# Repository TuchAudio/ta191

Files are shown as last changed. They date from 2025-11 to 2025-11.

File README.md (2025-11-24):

# ta191
Low Noise, improved Moving-Coil Phono Pre-Amp

## Purpose
An optional _previous_ stage for **MM Phono preamps** like [TuchAudio 101b](../../../ta101b), allowing the use of **Moving Coil** cartridges. _With suitable wiring_ it could be used with other preamps as well, like the [103](../../../ta103) board.

A _built-in relay_ allows the **same input connector** to be used with both **MC** (thru amplification) and **MM cartridges** (_bypassing_ it straight to the MM Phono stage)

## Design
The use of **four _common-base_ stages in parallel**  provides **low input impedance** (100 Ω) and **improved _signal-to-noise_ ratio** (by 6 dB).

_Symmetrical power supply_ thru **serial regulation** provides high PSRR.

## Specs
- **Power supply:** +/-9V, _symmetrical_ (just a few mA)
- **Gain:** x33 (+34 dB)
- **Input Sensitivity:** 0.11 mV over 100 Ω (for a 3.6 mV output, suitable for [TuchAudio 101b preamp](../../../ta101b) or [TuchAudio 103](../../../ta103))
- **Nominal Output level:** 3.6 mV over 110 kΩ (from a 0.11 mV input)
- **Output impedance:** 3.3 kΩ. _Lower load impedances are allowed, but diminished output level and impaired bass response are to be expected_.

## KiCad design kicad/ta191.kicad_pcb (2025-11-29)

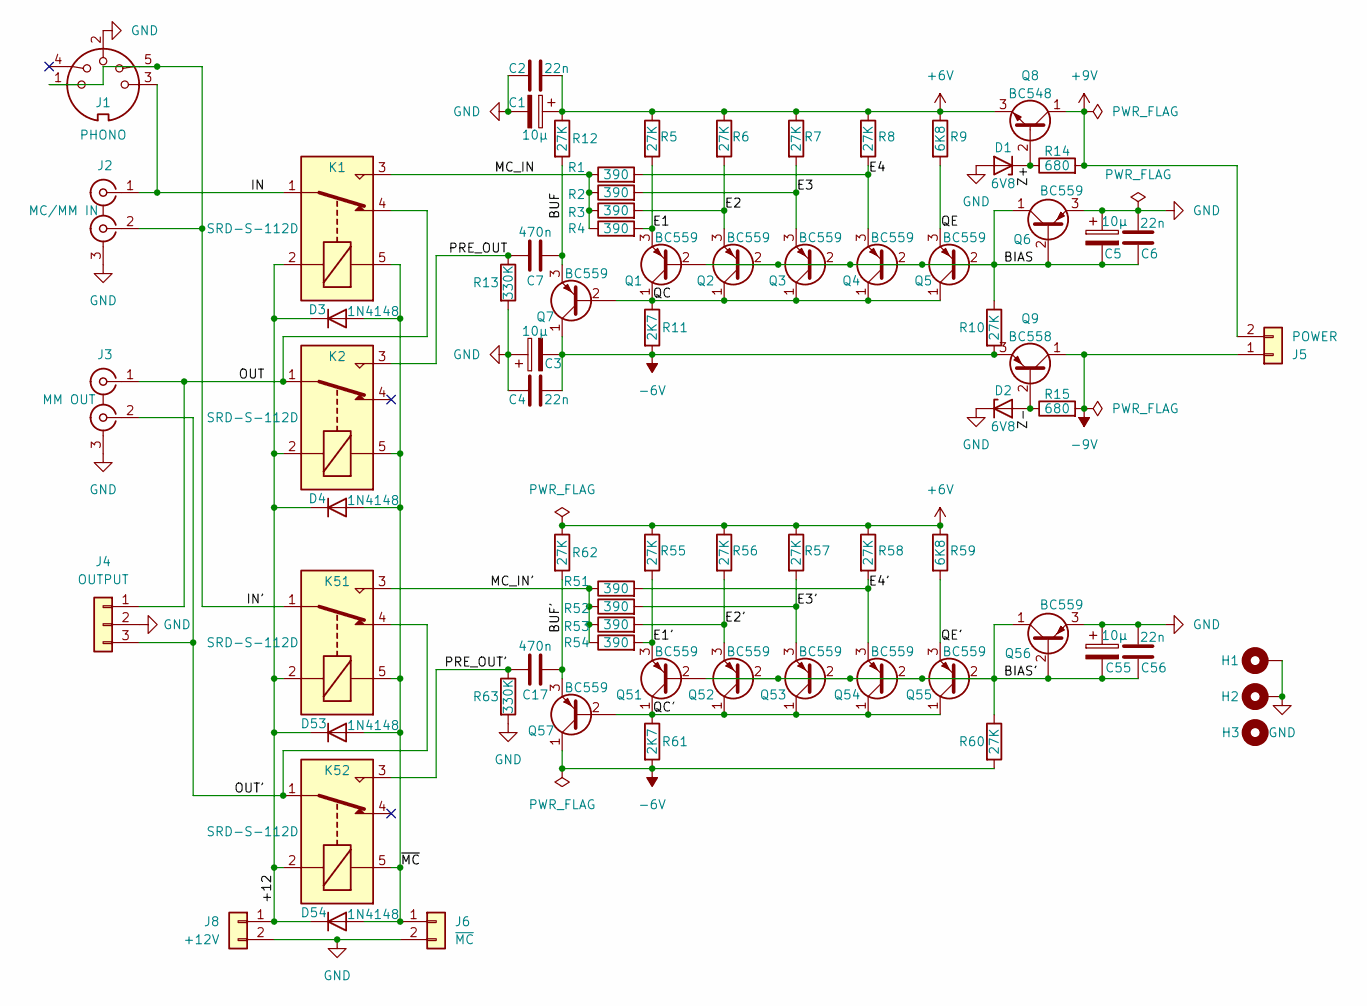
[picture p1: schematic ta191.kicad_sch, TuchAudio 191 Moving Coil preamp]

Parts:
C1, C3, C5, C55: 10µ; CP_Radial_D4.0mm_P1.50mm
C2, C4, C6, C56: 22n; C_Disc_D6.0mm_W2.5mm_P5.00mm
C7, C17: 470n; C_Rect_L7.2mm_W3.0mm_P5.00mm_FKS2_FKP2_MKS2_MKP2
D1, D2: 6V8; D_DO-35_SOD27_P7.62mm_Horizontal
D3, D4, D53, D54: 1N4148; D_DO-35_SOD27_P7.62mm_Horizontal
H1, H2: MountingHole_Pad; MountingHole_3.2mm_M3_DIN965_Pad
H3: MountingHole; MountingHole_3.2mm_M3
J1: PHONO; DIN 5-180deg
J2: MC/MM IN; 2xRCA_vertical
J3: MM OUT; 2xRCA_vertical
J4: OUTPUT; PinHeader_1x03_P2.54mm_Vertical
J5: POWER; PinHeader_1x02_P2.54mm_Vertical
J6: ~{MC}; PinHeader_1x02_P2.54mm_Vertical
J8: +12V; PinHeader_1x02_P2.54mm_Vertical
K1, K2, K51, K52: SRD-S-112D; Relay_SPDT_SANYOU_SRD_Series_Form_C
Q1, Q2, Q3, Q4, Q5, Q6, Q7, Q51, Q52, Q53, Q54, Q55, Q56, Q57: BC559; TO-92_Inline
Q8: BC548; TO-92_Inline
Q9: BC558; TO-92_Inline
R1, R2, R3, R4, R51, R52, R53, R54: 390; R_Axial_DIN0207_L6.3mm_D2.5mm_P10.16mm_Horizontal
R5, R6, R7, R8, R10, R12, R55, R56, R57, R58, R60, R62: 27K; R_Axial_DIN0207_L6.3mm_D2.5mm_P10.16mm_Horizontal
R9, R59: 6K8; R_Axial_DIN0207_L6.3mm_D2.5mm_P10.16mm_Horizontal
R11, R61: 2K7; R_Axial_DIN0207_L6.3mm_D2.5mm_P10.16mm_Horizontal
R13, R63: 330K; R_Axial_DIN0207_L6.3mm_D2.5mm_P10.16mm_Horizontal
R14, R15: 680; R_Axial_DIN0207_L6.3mm_D2.5mm_P10.16mm_Horizontal

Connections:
+6V: C1.1, C2.2, Q8.3 (E), R5.1, R6.1, R7.1, R8.1, R9.1, R12.1, R55.1, R56.1, R57.1, R58.1, R59.1, R62.1
+9V: J5.2, Q8.1 (C), R14.2
-6V: C3.2, C4.2, Q7.1 (C), Q9.3 (E), Q57.1 (C), R10.2, R11.2, R60.2, R61.2
-9V: J5.1, Q9.1 (C), R15.2
/+12: D3.1 (K), D4.1 (K), D53.1 (K), D54.1 (K), J8.1, K1.2, K2.2, K51.2, K52.2
/BIAS: C5.2, C6.2, Q1.2 (B), Q2.2 (B), Q3.2 (B), Q4.2 (B), Q5.2 (B), Q6.1 (C), Q6.2 (B), R10.1
/BIAS': C55.2, C56.2, Q51.2 (B), Q52.2 (B), Q53.2 (B), Q54.2 (B), Q55.2 (B), Q56.1 (C), Q56.2 (B), R60.1
/BUF: C7.2, Q7.3 (E), R12.2
/BUF': C17.2, Q57.3 (E), R62.2
/E1: Q1.3 (E), R4.2, R5.2
/E1': Q51.3 (E), R54.2, R55.2
/E2: Q2.3 (E), R3.2, R6.2
/E2': Q52.3 (E), R53.2, R56.2
/E3: Q3.3 (E), R2.2, R7.2
/E3': Q53.3 (E), R52.2, R57.2
/E4: Q4.3 (E), R1.2, R8.2
/E4': Q54.3 (E), R51.2, R58.2
/IN: J1.3, J2.1 (IN1), K1.1
/IN': J1.1, J1.5, J2.2 (IN2), K51.1
/MC_IN: K1.3, R1.1, R2.1, R3.1, R4.1
/MC_IN': K51.3, R51.1, R52.1, R53.1, R54.1
/OUT: J3.1 (IN1), J4.1, K1.4, K2.1
/OUT': J3.2 (IN2), J4.3, K51.4, K52.1
/PRE_OUT: C7.1, K2.3, R13.1
/PRE_OUT': C17.1, K52.3, R63.1
/QC: Q1.1 (C), Q2.1 (C), Q3.1 (C), Q4.1 (C), Q5.1 (C), Q7.2 (B), R11.1
/QC': Q51.1 (C), Q52.1 (C), Q53.1 (C), Q54.1 (C), Q55.1 (C), Q57.2 (B), R61.1
/QE: Q5.3 (E), R9.2
/QE': Q55.3 (E), R59.2
/Z+: D1.1 (K), Q8.2 (B), R14.1
/Z-: D2.2 (A), Q9.2 (B), R15.1
/~MC: D3.2 (A), D4.2 (A), D53.2 (A), D54.2 (A), J6.1, K1.5, K2.5, K51.5, K52.5
GND: C1.2, C2.1, C3.1, C4.1, C5.1, C6.1, C55.1, C56.1, D1.2 (A), D2.1 (K), H1.1, H2.1, J1.2, J2.3 (EXT), J3.3 (EXT), J4.2, J6.2, J8.2, Q6.3 (E), Q56.3 (E), R13.2, R63.2

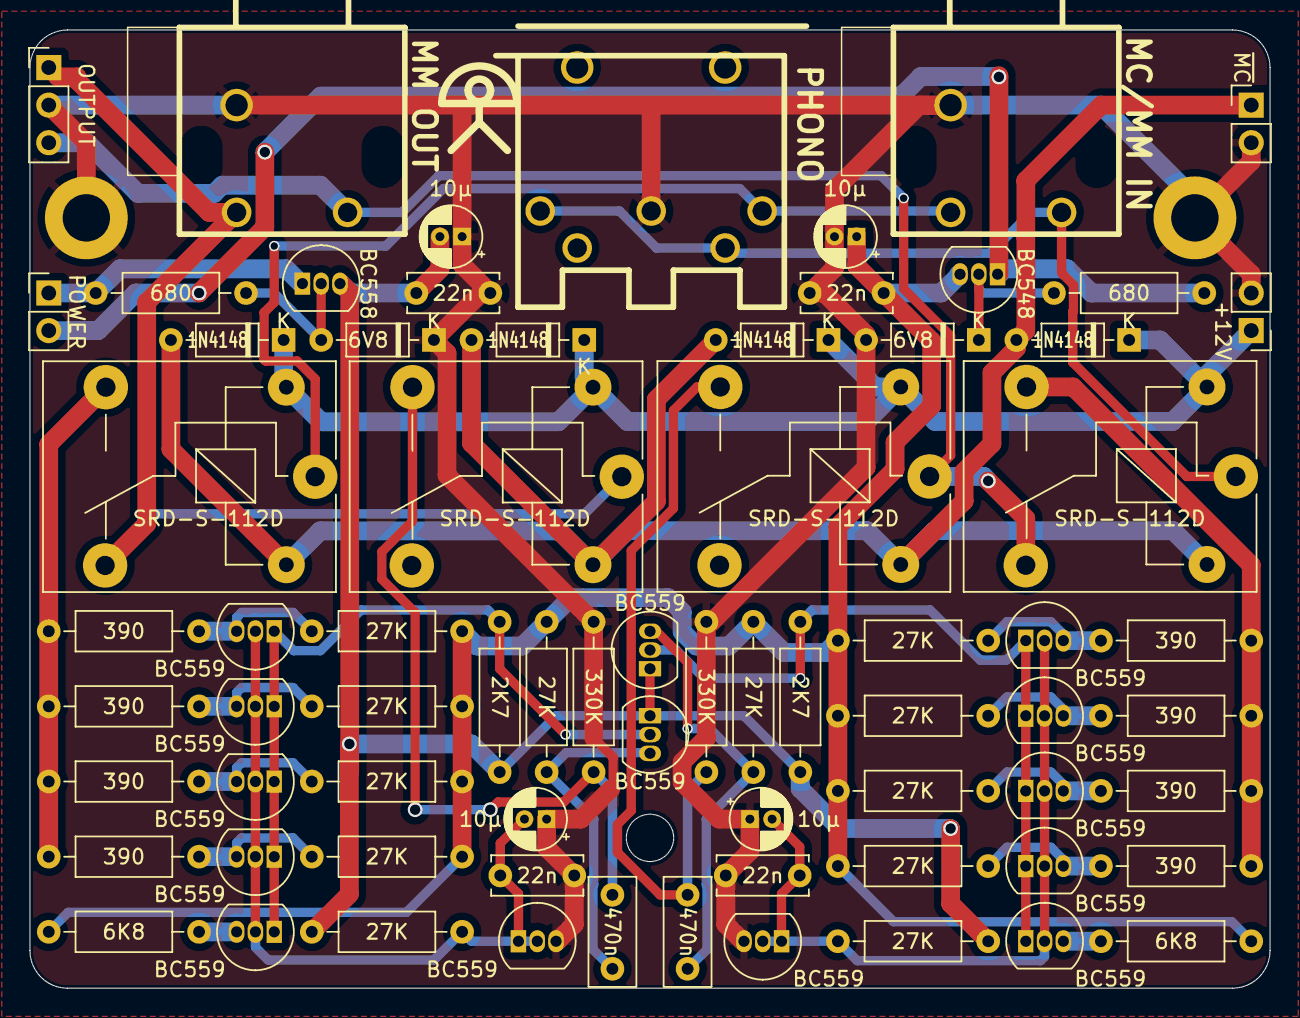
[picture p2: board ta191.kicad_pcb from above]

Board: 2 copper layers, 83.8 x 64.8 mm, 74 parts (0 on the bottom side), 33 nets.

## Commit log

2025-11-08 add KiCAD files
    [ta191.kicad_pcb, ta191.kicad_sch]
2025-11-29 fix mounting holes
    [ta191.kicad_pcb]
